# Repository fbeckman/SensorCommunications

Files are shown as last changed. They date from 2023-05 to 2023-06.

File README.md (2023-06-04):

# SensorCommunications
Die Anwendung basiert auf der Verwendung von batteriebetriebenen Temperatur- und Luftfeuchtigkeitssensoren zur Überwachung der Kühlgeräte in einem Laden. Die Sensoren nutzen die Kommunikationstechnologien ESPnow und LoRa, um mit einem zentralen Gateway zu kommunizieren. Das Gateway ist verantwortlich für die Erfassung der Messdaten und deren Weiterleitung an eine InfluxDB-Datenbank.

Die Sensoren werden strategisch in verschiedenen Bereichen des Ladens platziert, um eine umfassende Überwachung der Temperatur und Luftfeuchtigkeit sicherzustellen. Sie sind mit Batterien betrieben, um eine einfache Installation und flexible Positionierung zu ermöglichen. Die Sensoren erfassen kontinuierlich die aktuellen Werte für Temperatur und Luftfeuchtigkeit und senden diese Daten über ESPnow oder LoRa an das Gateway.

Das Gateway dient als zentraler Hub für die Datenkommunikation. Es empfängt die Messdaten von den Sensoren und leitet sie an die InfluxDB-Datenbank weiter. Die InfluxDB ist eine spezielle Zeitreihendatenbank, die sich gut für die Speicherung und Analyse von Sensordaten eignet. Dort werden die Messwerte in Echtzeit gespeichert und können für weitere Analysen und Auswertungen verwendet werden.

Zusätzlich zur Datenspeicherung bietet die Anwendung ein Dashboard, das Grafana verwendet. Grafana ist ein leistungsstarkes Open-Source-Tool zur Visualisierung und Analyse von Daten. Das Dashboard ermöglicht es den Benutzern, die aktuellen und historischen Messwerte der Temperatur und Luftfeuchtigkeit in Form von Grafiken und Diagrammen zu überwachen. Es bietet eine benutzerfreundliche Oberfläche, um die Daten in Echtzeit zu visualisieren und relevante Erkenntnisse daraus zu ziehen.

Um die Sicherheit und Zuverlässigkeit der Kühlgeräte zu gewährleisten, werden bei bestimmten Messwertüberschreitungen Alarmmeldungen generiert. Diese Meldungen werden über den Instant-Messaging-Dienst Telegram an die relevanten Benutzer gesendet. Benutzer können ihre Telegram-Konten mit der Anwendung verbinden, um Alarmmeldungen zu erhalten, wenn zum Beispiel die Temperatur in einem Kühlgerät einen kritischen Wert überschreitet. Diese Alarme ermöglichen es dem Ladenpersonal, schnell zu reagieren und potenzielle Probleme mit den Kühlgeräten zu beheben, um die Qualität und Sicherheit der gelagerten Waren zu gewährleisten.

Die Sensoren sind so konfiguriert, dass sie alle 30 Minuten eine Messung der Temperatur und Luftfeuchtigkeit durchführen. Zwischen den Messungen wechseln sie automatisch in einen Stromsparmodus, um Energie zu sparen. Dieser Modus reduziert den Energieverbrauch der Sensoren erheblich, indem sie in einen schlafenden Zustand versetzt werden. In diesem Zustand verbrauchen die Sensoren nur sehr wenig Strom und maximieren so die Lebensdauer der Batterien.

Die Zeitintervalle zwischen den Messungen können je nach den Anforderungen und der Sensorkonfiguration angepasst werden. In diesem Fall wurde eine Intervallzeit von 30 Minuten gewählt, um regelmäßige Messungen der Temperatur und Luftfeuchtigkeit sicherzustellen. Dieses Intervall kann jedoch entsprechend den spezifischen Anforderungen der Anwendung angepasst werden, z. B. wenn eine höhere oder niedrigere Frequenz der Messungen erforderlich ist.

Der Wechsel in den Stromsparmodus zwischen den Messungen hilft dabei, die Batterielebensdauer der Sensoren zu verlängern. Da die Sensoren normalerweise für eine längere Zeit im Ruhemodus verbringen, bevor sie wieder aktiv werden, können sie über einen längeren Zeitraum betrieben werden, ohne dass die Batterien ausgetauscht oder aufgeladen werden müssen. Dies ist besonders vorteilhaft in Situationen, in denen der Zugang zu den Sensoren erschwert sein kann oder in Umgebungen, in denen eine regelmäßige Wartung der Batterien nicht praktikabel ist.

Durch die Kombination der regelmäßigen Messungen mit dem Stromsparmodus wird eine effiziente und zuverlässige Überwachung der Kühlgeräte im Laden gewährleistet, während gleichzeitig die Lebensdauer der Sensorenbatterien maximiert wird.

Die Sensormodule basieren auf dem ESP8266 Mikrocontroller, einem weit verbreiteten und leistungsstarken Mikrocontroller für IoT-Anwendungen. Sie sind mit DHT11 Sensoren ausgestattet, die speziell für die Erfassung von Temperatur- und Luftfeuchtigkeitsdaten entwickelt wurden. Der ESP8266 Mikrocontroller ermöglicht die einfache Kommunikation mit den Sensoren und die Übertragung der erfassten Daten über ESPnow oder LoRa zum Gateway.

Für die Stromversorgung der Sensormodule werden 3,7V LiIon Akkus und 1,5V AAA LiIon Akkus verwendet. Diese Akkus bieten eine zuverlässige und langlebige Stromversorgung für die Sensoren. Die Verwendung von wiederaufladbaren LiIon Akkus ermöglicht es, die Batterien wiederholt aufzuladen und somit den Bedarf an häufigem Batteriewechsel zu reduzieren.

Das Gateway, das die Kommunikation zwischen den Sensormodulen und der InfluxDB-Datenbank ermöglicht, ist ebenfalls auf dem ESP8266 Mikrocontroller basiert. Es fungiert als zentraler Knotenpunkt, der die Messdaten von den Sensoren empfängt und sie zur weiteren Verarbeitung und Speicherung an die Datenbank sendet.

Die InfluxDB-Datenbank und die Dashboards werden auf einem Raspberry Pi installiert. Der Raspberry Pi ist ein beliebter und vielseitiger Einplatinencomputer, der häufig in IoT-Anwendungen eingesetzt wird. Er bietet genügend Rechenleistung und Speicherplatz, um die InfluxDB-Datenbank zu hosten und die Grafana-Dashboards auszuführen.

Die Entwicklungsumgebung für die Programmierung der Sensormodule und des Gateways ist Visual Studio Code, eine weit verbreitete und leistungsstarke Code-Editor-Plattform. Die Entwicklungsumgebung wird mit dem Plugin PlatformIO erweitert, das speziell für die Entwicklung von Mikrocontroller-basierten Projekten entwickelt wurde. PlatformIO bietet eine integrierte Entwicklungsumgebung mit Tools zur Programmierung, Fehlerbehebung und Überwachung von Mikrocontrollern.

Durch die Kombination von ESP8266 Mikrocontrollern, DHT11 Sensoren, LiIon Akkus, Raspberry Pi, InfluxDB, Grafana und der Entwicklungsumgebung Visual Studio Code mit PlatformIO entsteht eine robuste und leistungsstarke Anwendung zur Überwachung der Kühlgeräte in einem Laden.

Zum Erstellen dieser Beschreibung wurde ChatGPT verwendet.

Folgende Prompts führten zu dem Ergebnis:

- beschreibe eine Anwendung, die mit Hilfe von batteriebetriebenen Temperatur- und Luftfeuchtigkeitsensoren die Kühlgeräte in einem Laden aufzeichnet. Die Sensoren verwenden ESPnow und LoRa um mit einem Gateway zu kommunizieren. Das Gateway sendet die Messdaten an eine InfluxDB Datenbank. Es gibt ein Dashboard dass Grafana verwendet. Bei bestimmten Messwertüberschreitungen werden Alarm Meldungen über Telegram gesendet.

- ergänze: Die Sensoren messen alle 30 Minuten. Dazwischen gehen sie in einen Stromsparmodus.

- ergänze: die Sensormodule verwenden ESP8266 Mikrocontroller und DHT11 Sensoren. Als Batterien werden  3,7V  LiIon Akkus und 1,5V AAA LiIon Akkus verwendet. Das Gateway ist ebenfalls ESP8266 basiert. Die Datenbank und die Dashboards sind auf einem Raspberry Pi installiert. Die Entwicklungsplattform ist Visual Studio Code mit dem Plugin PlatformIO.

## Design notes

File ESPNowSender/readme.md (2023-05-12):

# ESPNowSender
ESPNowSender is used to measure temperature and humidity and send it to the ESPNowLoRaGateway. It also sends the voltage of its own battery to the ESPNowLoRaGateway.

ESPNowSender consists of an ESP8266-12F module and a DHT11 sensor mounted on a battery case for 2 AAA batteries. The batteries are rechargeable 1.5V LiIon batteries. 

To allow programming of the ESP module there are some additional pin connectors. One 6 pin connector for the FTDI232 USB to TTL adapter and two 2 pin connectors to set the module into programming mode.

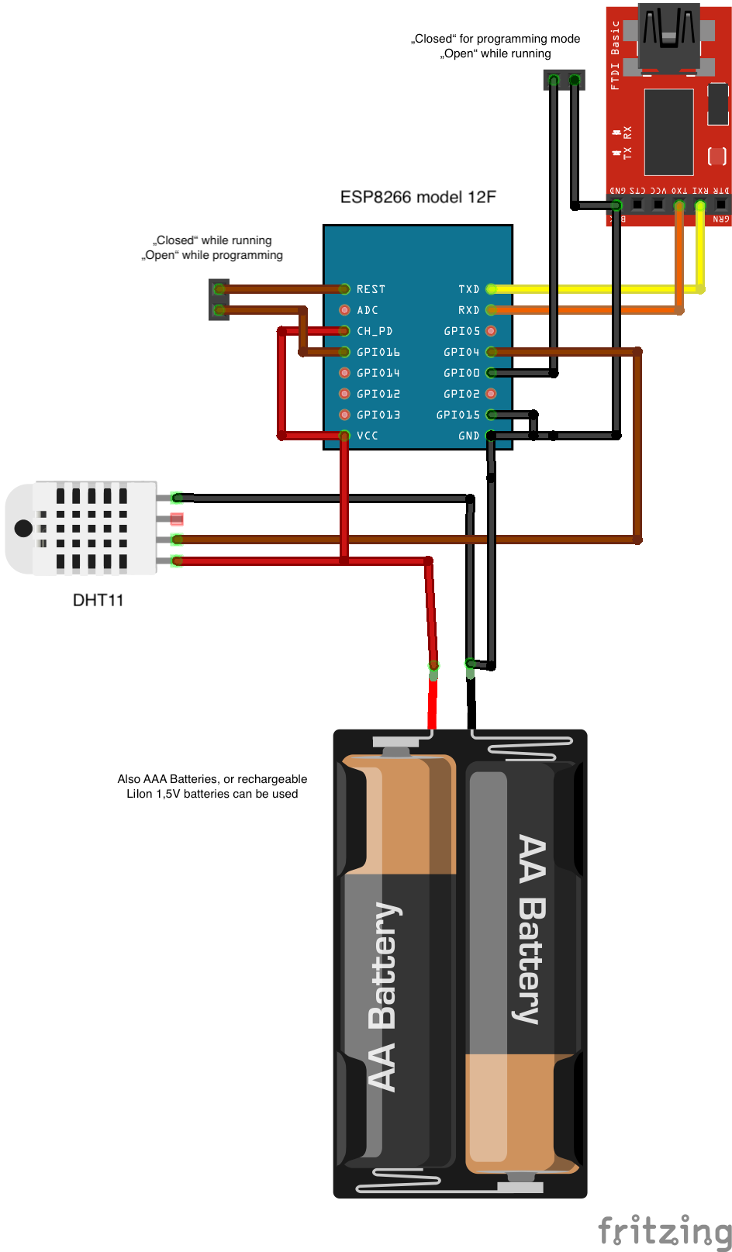
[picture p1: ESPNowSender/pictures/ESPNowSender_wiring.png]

<p>



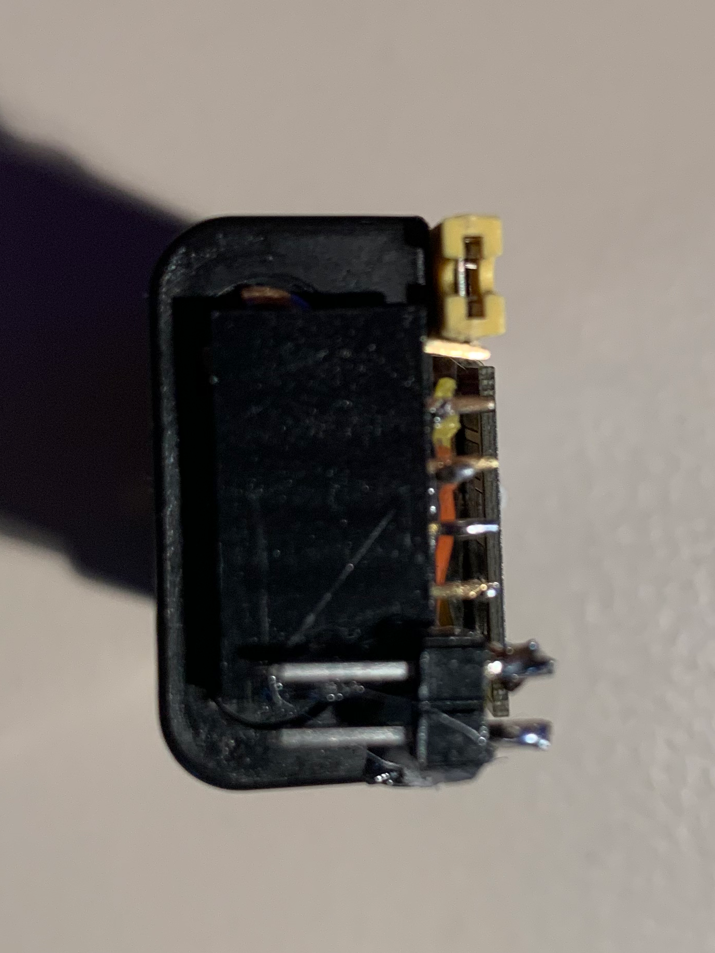
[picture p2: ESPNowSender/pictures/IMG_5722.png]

</p>

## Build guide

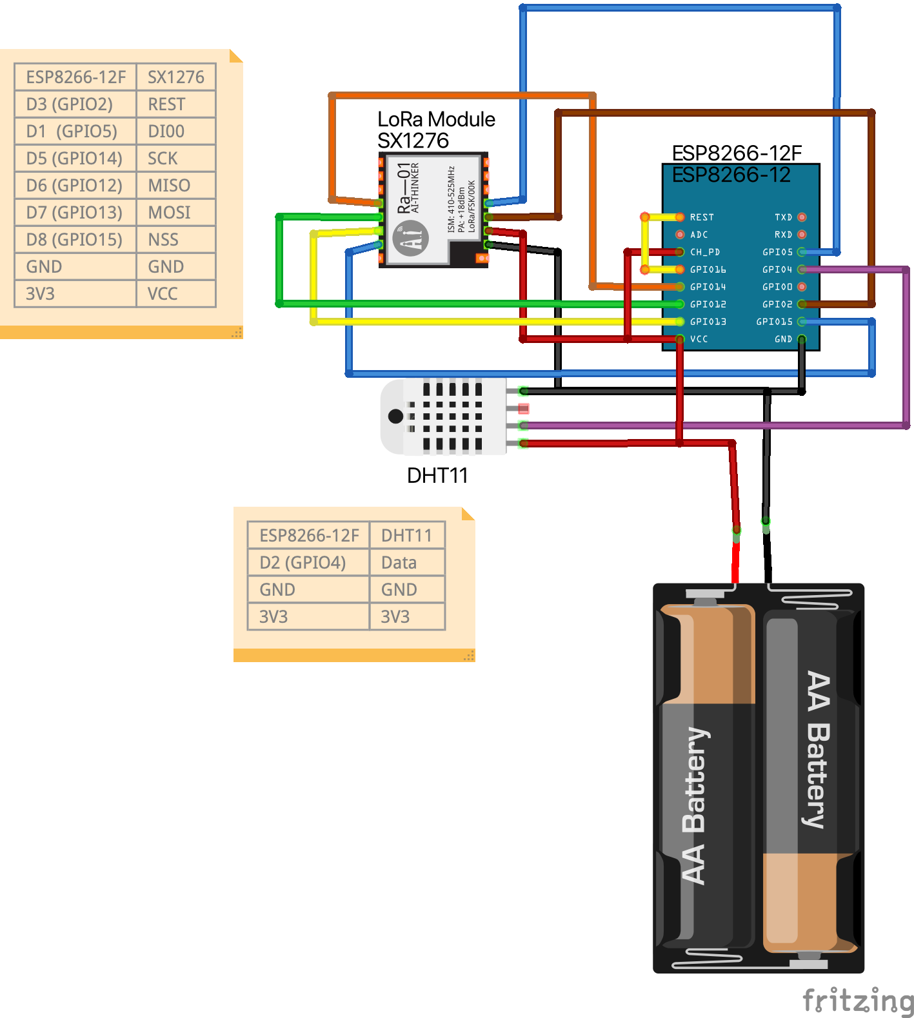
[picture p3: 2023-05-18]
LoRaSender/pictures/LoRaSender_wiring.png

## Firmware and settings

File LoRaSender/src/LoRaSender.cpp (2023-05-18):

#include <Arduino.h>
#include <DHT.h>
#include <Wire.h>
#include <LoRa.h>
#include <SPI.h>

#define SS D8
#define RST D3
#define DIO0 D1

#define BOARD_ID 13

// Use DHT11 sensor at D2
#define DHTPIN D2
#define DHTTYPE DHT11
DHT dht(DHTPIN, DHTTYPE);

ADC_MODE(ADC_VCC); // activate onboard measurement of battery voltage

typedef struct messageToBeSent {
  byte id;
  signed short temperature;
  short humidity;
  short voltage;
} struct_message;

messageToBeSent myMessageToBeSent;

void gotoSleep() {
  ESP.deepSleep(30*60e6); //sleep 30 minutes = 30 * 60e6 microseconds
  //ESP.deepSleep(15e6); //sleep 15 seconds for testing purposes
}  

void setup() {
  // Initialize DHT sensor
  dht.begin();
  // Reading temperature and humidity
  myMessageToBeSent.humidity = (short)(dht.readHumidity()*100);
  // Read temperature as Celsius
  myMessageToBeSent.temperature = (short)(dht.readTemperature()*100);
  if (isnan(myMessageToBeSent.humidity) || isnan(myMessageToBeSent.temperature)) {
    gotoSleep();
  } 
  // Read battery voltage
  myMessageToBeSent.voltage = (short)(((float)ESP.getVcc()/1024.0f)*100);
  myMessageToBeSent.id = BOARD_ID; 
  
  LoRa.setPins(SS, RST, DIO0);
  if (LoRa.begin(866E6)) {
    LoRa.setSpreadingFactor(12);
    LoRa.setSignalBandwidth(125000);
    LoRa.enableCrc();
    //LoRa.setTxPower(20);
    //Send data packets
    LoRa.beginPacket();
    LoRa.write((uint8_t *) &myMessageToBeSent, sizeof(myMessageToBeSent));
    LoRa.endPacket();
    LoRa.sleep();      
  }
  gotoSleep();
}

void loop() {
}

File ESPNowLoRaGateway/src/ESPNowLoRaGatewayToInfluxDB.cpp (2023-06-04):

// Import required libraries
#include <Arduino.h>
#include <ESP8266WiFi.h>
#include <InfluxDb.h>
#include <espnow.h>
#include <Credentials.h>
#include <Wire.h>
#include <SPI.h>
#include <LoRa.h>
#include <WiFiClientSecure.h>

uint8_t mac[6] {0xBC, 0xFF, 0x4D, 0x5F, 0x74, 0x48};
#define CHANNEL 1

// WiFi parameters
const char* ssid = "see Credentials.h";
const char* password = "see Credentials.h";

const char* dweetIoHost = "dweet.io";
const char* sensorBaseName = "b3d84112-a54c-4548-a0a1-4d9acdec7589";

//#define INFLUXDB_HOST "see Credentials.h"
Influxdb influx(INFLUXDB_HOST);

#define SS D8
#define RST D0
#define DIO0 D2

#define ESP_OK 0
typedef struct messageToBeReceived {
  byte id;
  signed short temperature;
  short humidity;
  short voltage;
} struct_message;

messageToBeReceived incomingReadings;
volatile bool doReadESPNow = false; // Flag set by callback to perform read process in main loop
volatile bool doReadLoRa = false; // Flag set by callback to perform read process in main loop
volatile int incomingPacketSize;

// callback function that will be executed when data is received
void onReceiveESPNow(uint8_t * mac_addr, uint8_t *incomingData, uint8_t len) { 
  doReadESPNow = true;
  memcpy(&incomingReadings, incomingData, sizeof(incomingReadings));
  Serial.printf("ESPnow message received. Packet size: %u\n", sizeof(incomingReadings));
}

void onReceiveLoRa(int packetSize) {
  doReadLoRa = true;
  if(packetSize == sizeof(incomingReadings)) {
    LoRa.readBytes((uint8_t *) &incomingReadings, sizeof(incomingReadings));
  }

  Serial.printf("LoRa message received. Packet size: %u\n", packetSize);
  // print RSSI of packet
  Serial.print("RSSI: ");
  Serial.println(LoRa.packetRssi());
}

void writeToInfluxDB() {
  float temperature = incomingReadings.temperature/100.0f;
  float humidity = incomingReadings.humidity/100.0f;
  float voltage = incomingReadings.voltage/100.0f;
  influx.setDb("HomeSensors");
  InfluxData row("Sensor" + String(incomingReadings.id));
  row.addValue("Temperatur", temperature);
  row.addValue("Relative Luftfeuchtigkeit", humidity);
  row.addValue("Spannung", voltage);
  influx.write(row);  

  Serial.printf("Board ID %u\n", incomingReadings.id);
  Serial.printf("temperature: %4.2f \n", temperature);
  Serial.printf("humidity: %4.2f \n", humidity);
  Serial.printf("voltage: %4.2f \n", voltage);
  Serial.println();
}

void writeToDweetIo() {
  float temperature = incomingReadings.temperature/100.0f;
  float humidity = incomingReadings.humidity/100.0f;
  float voltage = incomingReadings.voltage/100.0f;
  // Use WiFiClient class to create TCP connections
  WiFiClientSecure client;
  client.setInsecure();
  const int httpPort = 443;
  if (!client.connect("dweet.io", httpPort)) {
    Serial.println("connection to dweet.io failed");
    return;
  }   
  client.print(String("GET /dweet/for/") + String(sensorBaseName) + "?Sensor=" + String(incomingReadings.id) + "&temperature=" + String(temperature) + "&humidity=" + String(humidity) + "&voltage=" + String(voltage) + " HTTP/1.1\r\n" +
              "Host: " + dweetIoHost + "\r\n" + 
              "Connection: close\r\n\r\n"); 
  delay(10);
  
  // Read all the lines of the reply from server and print them to Serial
  while(client.available()){
    String line = client.readStringUntil('\r');
    Serial.print(line);
  }
}

void setupLoRa() {
  LoRa.setPins(SS, RST, DIO0);
 
  if (!LoRa.begin(866E6)) {
    Serial.println("Starting LoRa failed!");
    return;
  }
  LoRa.setSpreadingFactor(12);
  LoRa.setSignalBandwidth(125000);
  LoRa.enableCrc();
    // register the receive callback
  LoRa.onReceive(onReceiveLoRa);
 
  // put the radio into receive mode
  LoRa.receive();
}

void setupESPNow() {
  // Init ESP-NOW
  if (esp_now_init() != ESP_OK) {
    Serial.println("Error initializing ESP-NOW");
    return;
  }
  
  // Once ESPNow is successfully Init, we will register for recv CB to
  // get recv packer info
  esp_now_register_recv_cb(onReceiveESPNow);
}

void setupWiFi(){
  int n = WiFi.scanNetworks();
  int found = 0;
  
  // Set the device as a Station and Soft Access Point simultaneously
  WiFi.mode(WIFI_AP_STA);

  for (int i = 0; i < n; ++i) {
    if (WiFi.SSID(i)== ssid1 ) {
      ssid = ssid1;
      password = password1;
      found = 1;
      break;
    }
    if (WiFi.SSID(i)== ssid2) {
      ssid = ssid2;
      password = password2;
      found = 1;
      break;
    }
  }
  if (found == 0) {
    Serial.println("No known network found. Please try later again.");
    exit(0);
  }

  wifi_set_macaddr(0, const_cast<uint8*>(mac));
  wifi_promiscuous_enable(true);
  wifi_set_channel(CHANNEL);
  wifi_promiscuous_enable(false);
 
  // Set device as a Wi-Fi Station
  WiFi.begin(ssid, password);
  while (WiFi.status() != WL_CONNECTED) {
    delay(1000);
    Serial.println("Setting as a Wi-Fi Station..");
  }

  Serial.print("Station IP Address: ");
  Serial.println(WiFi.localIP());
  Serial.print("Wi-Fi Channel: ");
  Serial.println(WiFi.channel());
  Serial.print("Station MAC Address: ");
  Serial.println(WiFi.macAddress());  
}

void setup() {
  // Initialize Serial Monitor
  Serial.begin(115200);
  
  setupWiFi();

  setupESPNow();
  setupLoRa();

}

void loop() {
   if (doReadESPNow) {
    writeToInfluxDB();
    writeToDweetIo();
    doReadESPNow = false; // Set flag back to false so next read will happen only after next ISR event
  }  
  if (doReadLoRa) {
    writeToInfluxDB();
    writeToDweetIo();
    doReadLoRa = false; // Set flag back to false so next read will happen only after next ISR event
  }  
}

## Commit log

2023-05-05 use signed short for temperature
    [ESPNowLoRaGatewayToInfluxDB.cpp, LoRaSender.cpp]
2023-05-12 wiring diagram fritzing
2023-05-15 Wiring LoRaSender
    [LoRaSender.fzz]
2023-05-18 LoRaSender without Telegram message
    [LoRaSender.fzz]
2023-06-04 Fixe MAC Adresse und fixer WiFi Kanal
    [ESPNowLoRaGatewayToInfluxDB.cpp]
2023-06-04 Update Credentials.h
    ssid und password für zwei WLANs
